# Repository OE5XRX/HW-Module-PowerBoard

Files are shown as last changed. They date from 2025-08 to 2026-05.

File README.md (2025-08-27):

# HW-Module-PowerBoard

## License

This project is licensed under [CERN-OHL-S-2.0](https://choosealicense.com/licenses/cern-ohl-s-2.0/).

## Badges

<br>
<br>
<br>
<br>
<br>

## Contact

OE5XRX Amateur Radio Club<br>
🌐 https://oe5xrx.org<br>
✉️ info@oe5xrx.org<br>

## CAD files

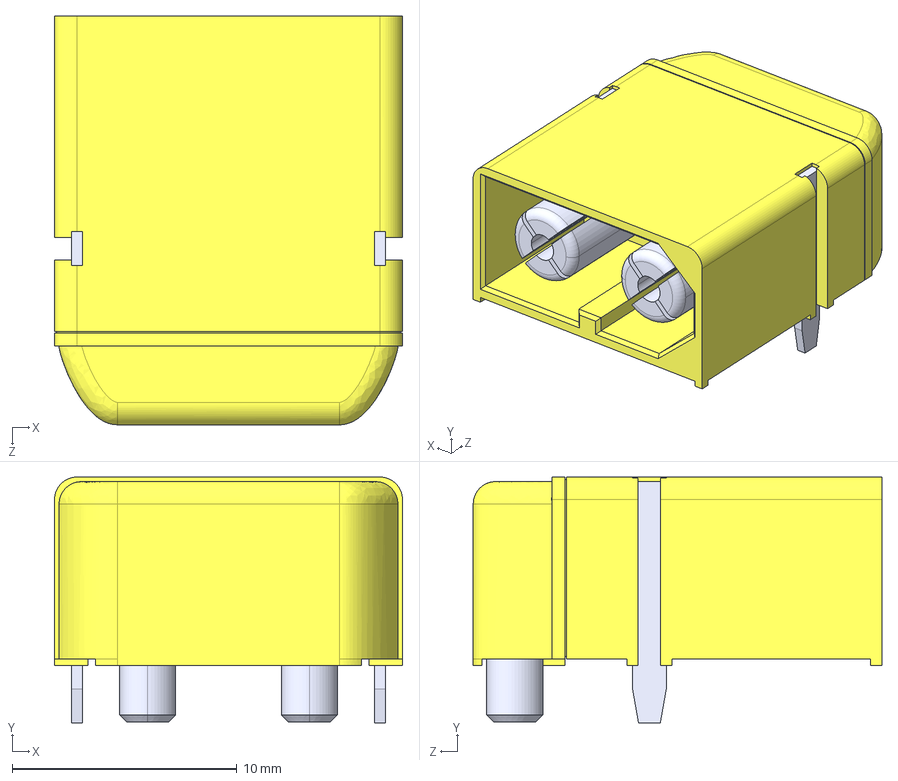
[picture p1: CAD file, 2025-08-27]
3d-models/XT60PW-M.step
15.5 x 11.0 x 18.2 mm

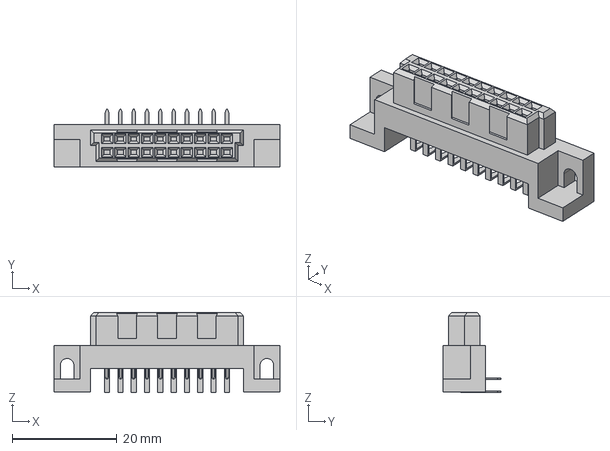
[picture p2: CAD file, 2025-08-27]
3d-models/PCN10C-20S-2.54DS.stp
43.1 x 11.0 x 15.3 mm

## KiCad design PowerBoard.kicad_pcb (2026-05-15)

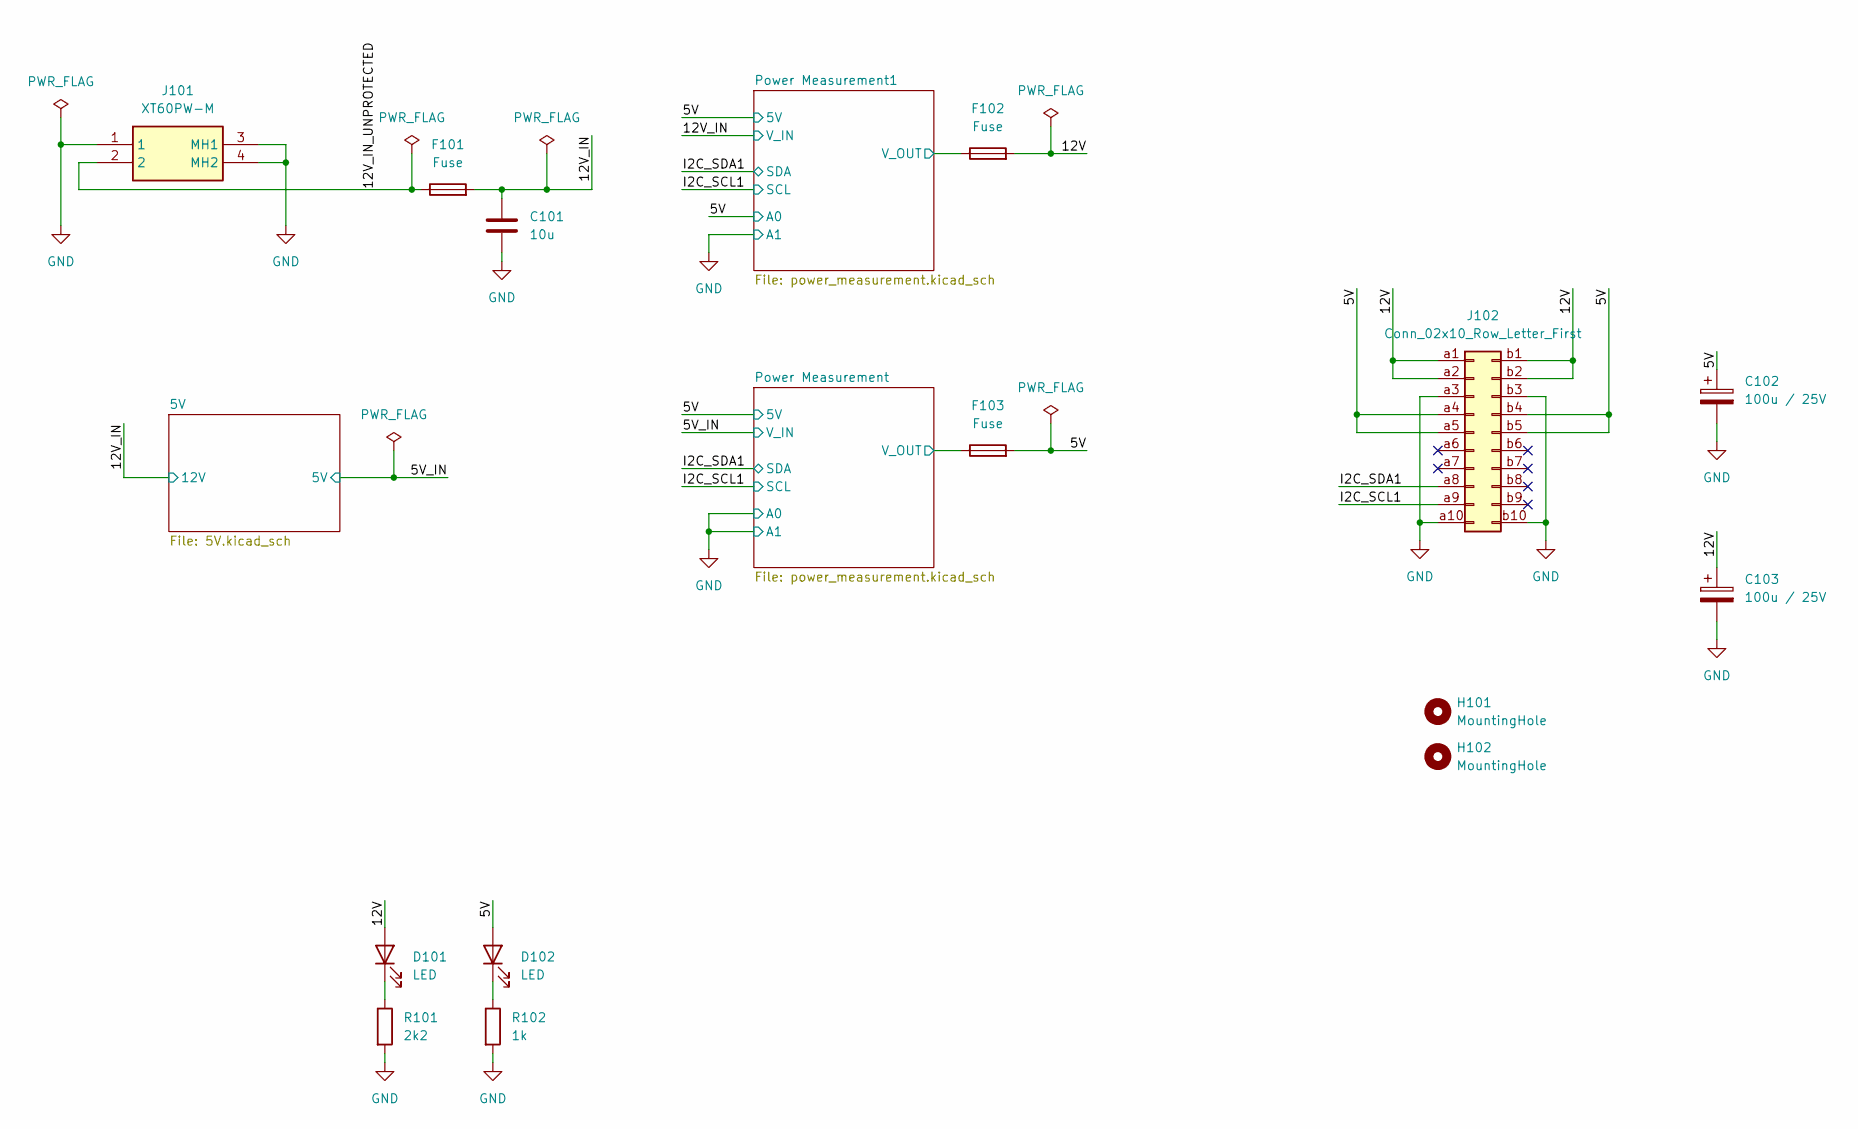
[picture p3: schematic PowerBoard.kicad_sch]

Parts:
C101: 10u; C_1206_3216Metric; LCSC C13585
C102, C103: 100u / 25V; CP_EIA-7343-43_Kemet-X; LCSC C132558
D101, D102: LED; LED_0805_2012Metric; LCSC C84256
F101, F102, F103: Fuse; FUSE_01530007Z; MOUSER 576-01530007Z
H101, H102: MountingHole; MountingHole_3.2mm_M3
J101: XT60PW-M; XT60PWM
J102: Conn_02x10_Row_Letter_First; PCN10C-20S-2.54DS; MOUSER 798-PCN10C20S254DS72
R101: 2k2; R_0805_2012Metric; LCSC C17520
R102: 1k; R_0805_2012Metric; LCSC C17513

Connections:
/5V: C102.1, D102.2 (A), F103.2, J102.a4, J102.a5, J102.b4, J102.b5; also elsewhere on the board
/12V: C103.1, D101.2 (A), F102.2, J102.a1, J102.a2, J102.b1, J102.b2
/12V_IN: C101.1, F101.2; also elsewhere on the board
/12V_IN_UNPROTECTED: F101.1, J101.2
/I2C_SCL1: J102.a9; also elsewhere on the board
/I2C_SDA1: J102.a8; also elsewhere on the board
/Power Measurement1/V_OUT: F102.1; also elsewhere on the board
/Power Measurement/V_OUT: F103.1; also elsewhere on the board
GND: C101.2, C102.2, C103.2, J101.1, J101.3 (MH1), J101.4 (MH2), J102.a3, J102.a10, J102.b3, J102.b10, R101.2, R102.2; also elsewhere on the board
unnamed: D101.1 (K), R101.1
unnamed: D102.1 (K), R102.1

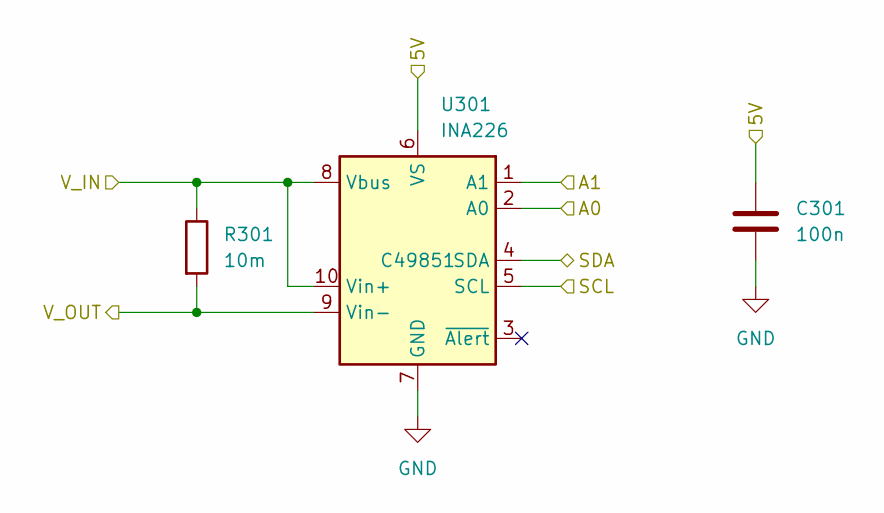
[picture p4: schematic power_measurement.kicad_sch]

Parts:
C301: 100n; C_0805_2012Metric; LCSC C28233
R301: 10m; R_2512_6332Metric; MOUSER 652-CRF2512FZR010ELF
U301: INA226; VSSOP-10_3x3mm_P0.5mm; LCSC C49851

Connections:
/5V: C301.1, U301.6 (VS); also elsewhere on the board
/5V_IN: R301.1, U301.8 (Vbus), U301.10 (Vin+); also elsewhere on the board
/I2C_SCL1: U301.5 (SCL); also elsewhere on the board
/I2C_SDA1: U301.4 (SDA); also elsewhere on the board
/Power Measurement/V_OUT: R301.2, U301.9 (Vin-); also elsewhere on the board
GND: C301.2, U301.1 (A1), U301.2 (A0), U301.7 (GND); also elsewhere on the board

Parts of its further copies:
C401: 100n; C_0805_2012Metric; LCSC C28233
R401: 10m; R_2512_6332Metric; MOUSER 652-CRF2512FZR010ELF
U401: INA226; VSSOP-10_3x3mm_P0.5mm; LCSC C49851

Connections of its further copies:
/5V: C401.1, U401.2 (A0), U401.6 (VS); also elsewhere on the board
/12V_IN: R401.1, U401.8 (Vbus), U401.10 (Vin+); also elsewhere on the board
/I2C_SCL1: U401.5 (SCL); also elsewhere on the board
/I2C_SDA1: U401.4 (SDA); also elsewhere on the board
/Power Measurement1/V_OUT: R401.2, U401.9 (Vin-); also elsewhere on the board
GND: C401.2, U401.1 (A1), U401.7 (GND); also elsewhere on the board

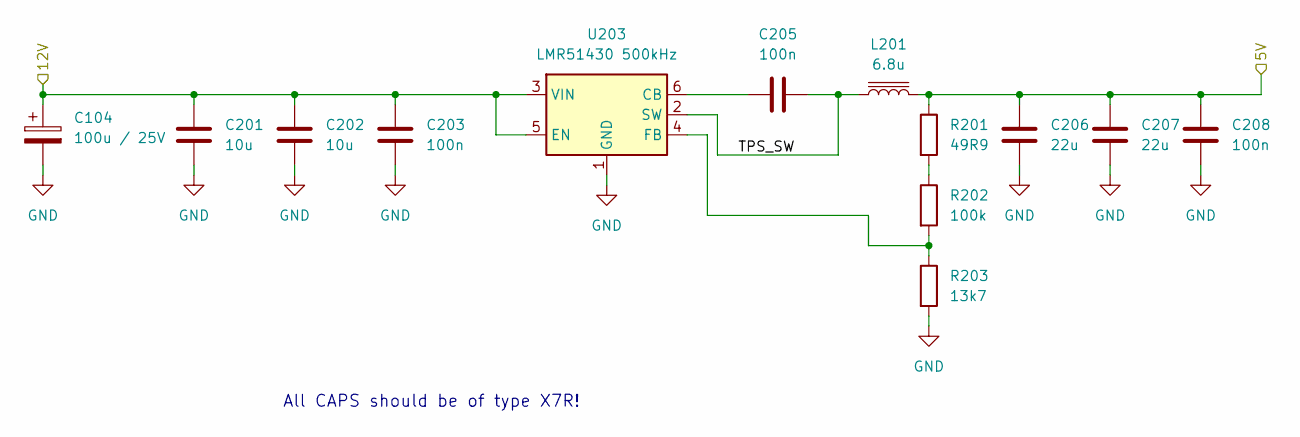
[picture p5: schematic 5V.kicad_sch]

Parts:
C104: 100u / 25V; CP_EIA-7343-43_Kemet-X; LCSC C132558
C201, C202: 10u; C_1206_3216Metric; LCSC C13585
C203, C205, C208: 100n; C_0805_2012Metric; LCSC C28233
C206, C207: 22u; C_1206_3216Metric; LCSC C12891
L201: 6.8u; WE-XHMI_6060; MOUSER 710-74439346068
R201: 49R9; R_0805_2012Metric; MOUSER 667-ERA-6AED49R9V
R202: 100k; R_0805_2012Metric; MOUSER 603-RC0805JR-07100KL
R203: 13k7; R_0805_2012Metric; MOUSER 652-CR0805FX-1372ELF
U203: LMR51430 500kHz; SOT-23-6; MOUSER 595-LMR51430XDDCR

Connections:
/5V/TPS_SW: C205.2, L201.1, U203.2 (SW)
/5V_IN: C206.2, C207.2, C208.2, L201.2, R201.1; also elsewhere on the board
/12V_IN: C104.1, C201.1, C202.1, C203.1, U203.3 (VIN), U203.5 (EN); also elsewhere on the board
GND: C104.2, C201.2, C202.2, C203.2, C206.1, C207.1, C208.1, R203.2, U203.1 (GND); also elsewhere on the board
unnamed: R201.2, R202.1
unnamed: C205.1, U203.6 (CB)
unnamed: R202.2, R203.1, U203.4 (FB)

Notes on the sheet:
All CAPS should be of type X7R!

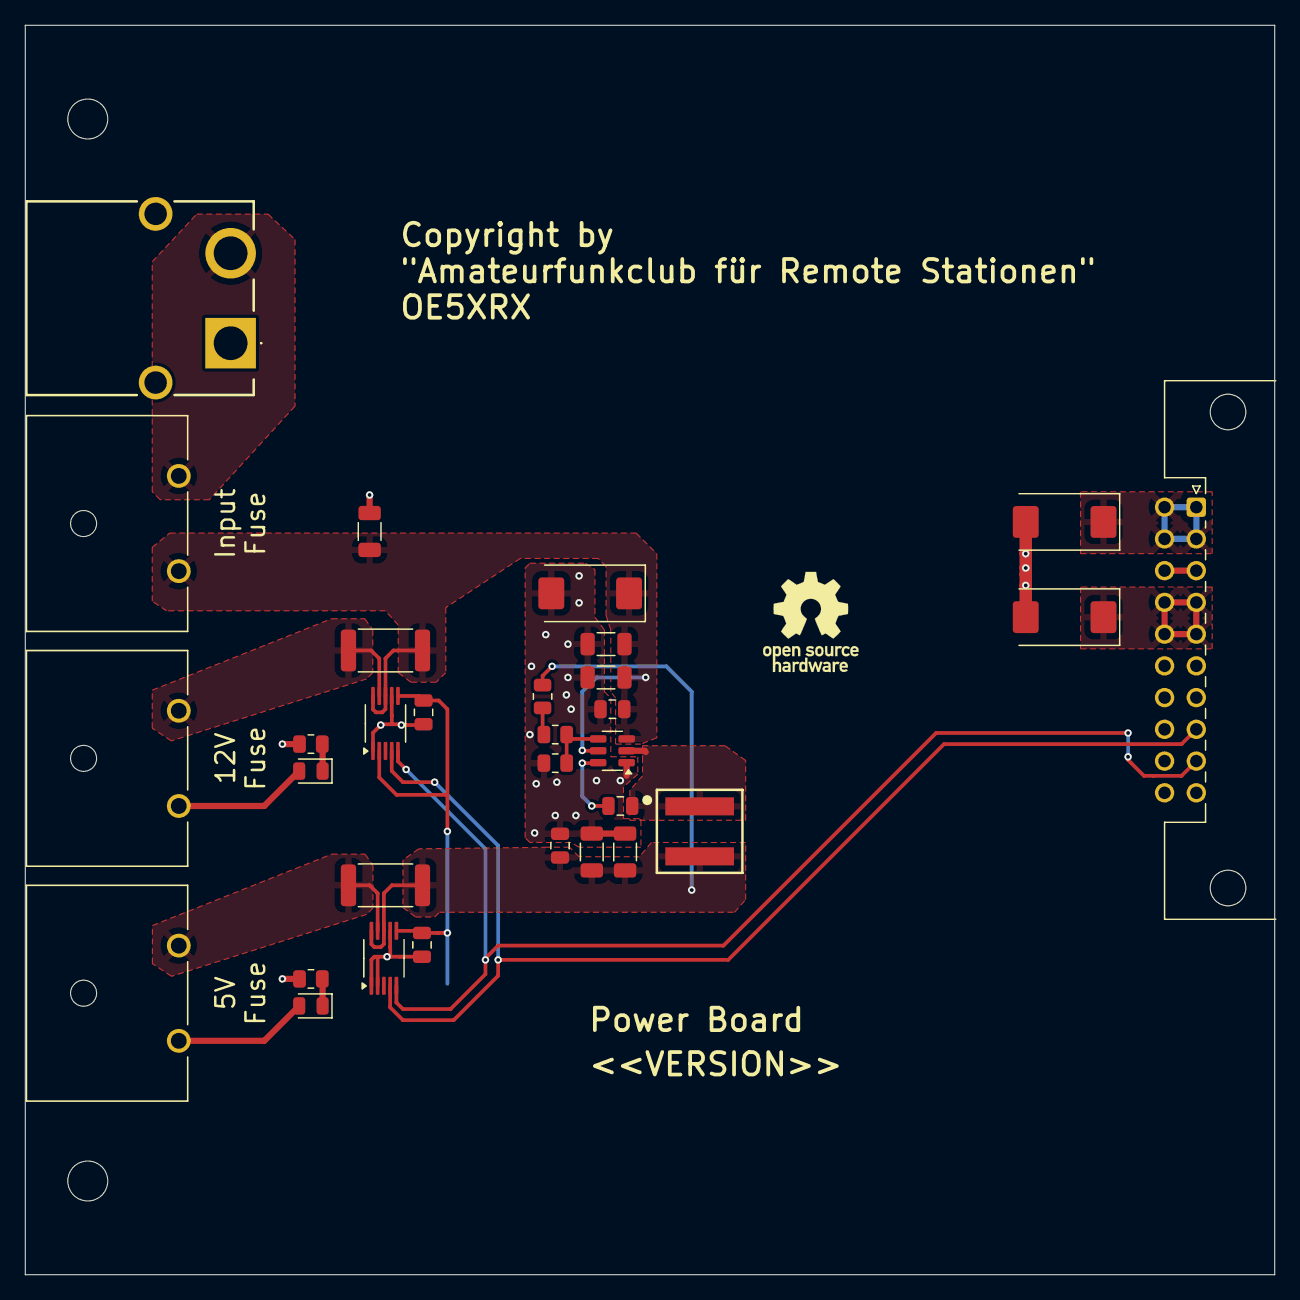
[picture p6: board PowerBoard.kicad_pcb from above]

Board: 4 copper layers, 100.0 x 100.0 mm, 33 parts (0 on the bottom side), 16 nets.

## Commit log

2025-08-27 setup project
    [5V.kicad_sch, PCN10C-20S-2.54DS.stp, XT60PW-M.step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]
2025-08-28 fix path for external components
    [main.kicad_pcb, main.kicad_sch]
2025-09-05 🔄 synced local '.github/workflows/create-debug-docs.yaml' with remote '.github/workflows/create-debug-docs.yaml'
2025-09-05 🔄 created local 'doc/_config.yml' from remote 'doc/_config.yml'
2025-09-05 🔄 created local 'doc/favicon.ico' from remote 'doc/favicon.ico'
2025-09-05 🔄 created local 'Gemfile' from remote 'Gemfile'
2026-05-12 rename(kicad): main.kicad_* → PowerBoard.kicad_*
    [PowerBoard.kicad_pcb, PowerBoard.kicad_sch]
2026-05-12 docs: rewrite Power index.md with overview, block-diagram, INA226 ranges, bringup
    Adds:
    - 1-sentence description front-matter (SEO + just-the-docs side-nav)
    - Übersicht paragraph linking to BusBoard and CM4Carrier
    - Mermaid block-diagram of the +12V/+5V flow
    - Versorgung table (input, +12V passthrough, +5V buck)
    - I²C measurement table with computed full-scale current and resolution
    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
    [power_data.kicad_sch]
2026-05-12 ci: retrigger after HW-Module-CI image pin to 1.8.5-7_k9.0.7
2026-05-13 fix(docs): INA226 Strom-Auflösung ist konfigurierbar, nicht 125 µA/LSB
    Copilot-Review-Befund auf PR #6 (L54): Der Wert '125 µA/LSB' war falsch
    hergeleitet (VShunt-LSB durch Shunt-Widerstand geteilt → ergibt nicht
    die Current-Register-Auflösung).
    Die INA226 Strom-Auflösung wird über das CALIBRATION-Register
    festgelegt: Current_LSB = max_expected_current / 32768. Bei 8 A
    Vollausschlag wäre das ≈250 µA/LSB; der Wert ist treiberabhängig
    und nicht durch den 10 mΩ Shunt fixiert.
    Neben­korrektur: VShunt-LSB ist 2.5 µV/LSB (nicht 1.25 µV/LSB wie
    in der vorherigen Version implizit angenommen).
2026-05-15 chore: migrate <<HASH>> placeholder to <<VERSION>> (#8)
    Aligns the KiCad title-block placeholder with the new versioning concept
    documented at oe5xrx.org/docs/remote-station/hardware/versioning/.
    The placeholder is substituted at CI time:
    - Release build: v1.5 → "1.5" (semver only, no `v`, no SHA)
    - Debug build: "BETA-<short-commit>"
    No electrical or layout change — pure text replacement on the title-block
    silkscreen text. Requires HW-Module-CI feat/version-placeholder
    (OE5XRX/HW-Module-CI#4) to be merged first; otherwise CI substitutes
    the old <<HASH>> token and leaves the new <<VERSION>> string literal
    in the title block until the CI side catches up.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
    [PowerBoard.kicad_pcb]
2026-05-15 fix(sch): add title_block with <<VERSION>> placeholder to all 3 schematics (#10)
    PowerBoard's schematics never had a title_block at all — the version
    field stayed empty in the rendered schematic PDF even after Phase 3
    placeholder migration, because there was no <<VERSION>> token to
    substitute.
    All other 5 HW-Module-* repos follow the convention:
    (title_block
    (title "<sheet name>")
    (rev "<<VERSION>>")
    (company "Amateurfunkclub für Remote Stationen")
    )
    Insert the same block into PowerBoard.kicad_sch, 5V.kicad_sch and
    power_measurement.kicad_sch with sheet-appropriate titles.
    Surfaced when the v1.0 deploy showed the version on the PCB silkscreen
    but the schematic PDF titl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
    [5V.kicad_sch, PowerBoard.kicad_sch, power_measurement.kicad_sch]

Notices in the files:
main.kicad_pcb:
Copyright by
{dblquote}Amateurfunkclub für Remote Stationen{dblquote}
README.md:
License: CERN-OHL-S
